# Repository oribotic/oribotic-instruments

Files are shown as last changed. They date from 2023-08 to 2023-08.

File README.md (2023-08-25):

Oribotic Instruments
====================

_Why wait for a Holtzman drive to fold space when you can start folding sound, now!_

Oribotic Instruments are multi-modal capacitive sensing instruments. They afford keypad style touch, pressure sensitive "soft touch" and capacitive sensing between electrode panels (rigid PCBs on flexible substrates such as textiles) otherwise known as _Fold Sensing_.

Copyright (c) 2023 Matthew Gardiner

MIT License

Software, hardware and instrument build contributions from: Simon Schmid, Dan Wilcox https://danomatika.com, Alexandre Bezri, Anna Oelsch

Description
-----------

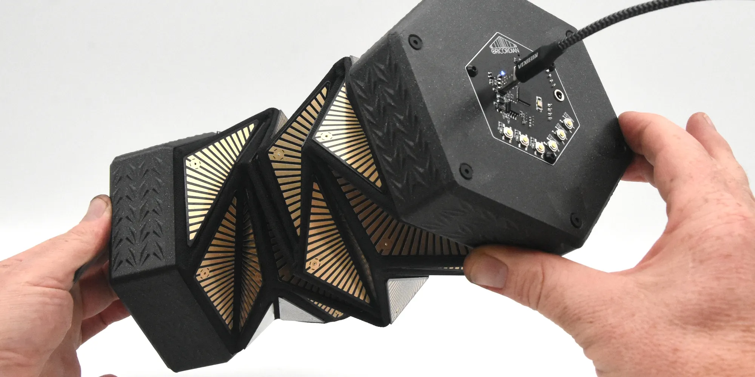
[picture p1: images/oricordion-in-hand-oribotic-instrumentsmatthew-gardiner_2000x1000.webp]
oribotic instruments


Our question for this work, What happens to our experience of space when we fold sound? is situated in our research into fundamental artistic methods for origami and robotics, following our central theme of Fold Sensing. Our conceptual approach is to invent foldable musical spaces rather than linear musical scores. The performer can explore the musical volume using choreographed folding paths and geometric gestures. 

Technically, oribotic instruments are layered electronics and textiles. The main elements are a capacitive sensor array from printed circuit board electrodes crafted as kinetic origami structures. The fold angles are captured in real-time and conveyed through a normalisation algorithm that adjusts for the non-linear capacitive response to the fold angle. These parametrised folded structures offer new affordances to interact, play and perform by contracting and expanding the fold geometry.

oribotic instruments multi-modal interations

Structure
---------

* `oribotic-instrument-atmega32u4`: instrument Arduino firmware
* `puredata`: [Puredata](https://puredata.info) abstraction library and templates

Installation & Build
--------------------

For info on building and configuring the Arduino firmware, see `oribotic-instrument-atmega32u4/README.md`

Usage
-----

Communication of the instrument with host systems is either via OSC (Open Sound Control) messages over a serial port *or* MIDI. The `comms-spec.md` markdown file lists the messaging specification for both types. Any software that can connect to a serial port or send/recieve MIDI messages should be able to receive from an Oribotic instrument.

Each foldable instrument is composed of a number of panels (8, 12, or 48) which are capcitively touch-sensitive and send the following for each panel in realtime:
* digital touch: on/off touch events
* bend: bend amount to the adjacent panel between unfolded and folded states (requires calibration)
* soft touch: amount of capacitive touch (think proximity and area/size)

As the instrument can be folded in an open-ended manner, calibration is required to send the bend low and high states: folded and unfolded, respectively. For instance, an 8 panel instrument could be folded in half, crosswise, in an origami pattern, etc the user only needs to tell the instrument when it is folded and unfolded. Panel bend values are then scaled to match.

### Puredata

An abstraction library and various templates and examples are provided both for the open-source [Puredata](https://puredata.info) computer music environment. 

Attribution
-----------

Funded through the FWF Austrian Science Fund, PEEK Program, ORI*botics on the art and science of origami and robotics https://orilab.art
Thank you to the Ars Electronica Futurelab https://ars.electronica.art/futurelab/
Thank you to [Josh Gardiner](https://github.com/NeuralSpaz) for pcb reviews and for being an awesome bro!

attribution logos

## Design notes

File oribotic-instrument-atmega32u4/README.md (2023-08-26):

Oribotic Instruments Arduino project
=====================================

Arduino based firmware for Oribotic instruments

Dependencies
------------

The project uses the following open source libraries:
* [MPR121](https://github.com/BareConductive/mpr121): MPR121 capacitive touch sense IC (modified, included in this repo)
* [OSC](https://github.com/CNMAT/OSC): (Open Sound Control) communication
* [MIDIUSB](https://github.com/arduino-libraries/MIDIUSB): MIDI communication over USB

Install the following libraries via the Arduino IDE Library Manager: OSC, MIDIUSB

Configuration
-------------

Configuration is set via defines at the top of `instrument_config.h`

Important compile-time settings are:

* `OSC`: 0 - disable, 1 - build with OSC serial communication
* `MIDI`: 0 - disable, 1 - build with MIDI communication
* `DEBUG_LEVEL`: 0 - off, 1 - error, 2 - info, 3 - debug
* `ORIGAMI`: YOSHIMURA - 8 panel, SUKI - 12 panel, KRESLING - 48 panel 
* `ROOTNOTE`: root MIDI note

The Arduino has too little memory for both OSC and MIDI communication, so you have to choose one and one only.

For example, this will run in MIDI mode:

~~~C
#define MIDI 1
#define OSC 0
~~~

This will run in OSC mode:

~~~C
#define MIDI 0
#define OSC 1
~~~

A bit further down in the file is:

~~~C
#define KRESLING 1
#define YOSHIMURA 2
#define SUKI 3
#define ORIGAMI YOSHIMURA
~~~

Update the last line, to KRESLING, YOSHIMURA or SUKI to suit the build of your instrument.

Associated config files for each instrument type:

* **KRESLING 48 panel** - see instrument_K48.h
* **SUKI 12 panel** - see instrument_S12.h
* **YOSHIMURA 8 panel** - see instrument_Y8.h

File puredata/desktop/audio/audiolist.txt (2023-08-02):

1 audio/flowcrash/Elkes.wav,
2 audio/flowcrash/8th-jubilee-rain-stereo.wav,
3 audio/flowcrash/Stillensteinklam.wav,
4 audio/flowcrash/bbc-milling-machine.wav,
5 audio/flowcrash/bbc-papermaking.wav,
6 audio/flowcrash/bbc-treadle-sewing-machine.wav.wav

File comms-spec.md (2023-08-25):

# AFFORDANCES

Using the MPR121's touch register in addition to filtered and baseline data from the MPR121, we identified four unique of gestural affordances from these instruments electrodes.

1. **Touch and Release**: the MPR121 is designed to identify touch and release interactions to each electrode. As a boolean value, these signals are useful for triggering samples or notes. 
2. **Soft Touch**: examining the filtered data following a touch and before a release affords a calculation of pressure on the sensor, as increased or decreased pressure is measurable, in small amounts. As an integer value with low range, small adjustments to volume on a sample, i.e. press harder = volume up, press lighter = volume down.
3. **Fold Sensing**: examining the filtered data at all times affords an approximation of proximity to another object. In the case of performance this can be the adjacent panel or the performer. The sensor gives no indication to the nature of the object, only that it is closer or further away. This makes for a very sensitive instrument. With a mathematical adjustment, derived from experimental test data with identical electrode pairs, we are able to estimate the angular position between the electrodes. The result is an integer value, reported as raw (MPR121->filtered) or bend range as defined during calibration, the value is generally scaled to 0-254 for OSC or 0-127 for MIDI and can be used for controlling of sound parameters. A simple example is the volume of a sound sample, a more complex use is to link the bend to one or more parametric audio operations. See Fold Sensing for detail on the sensing and calculation process.
4. **Fold Structure Sensing**: monitoring multiple electrodes to identify specific origami gestures  groups are defined using binary for code optimisation. Each panel occupies a position in the binary string. In the case of the Kresling origami, the panels are arranged in columns of 8 panels, where each binary digit refers to the one or off state of one of 8 panels, with six thereof. A panel group is defined by a switching a panel "on" in the group. Using binary, a single panel group only occupies six bytes in memory, and it describes the on or off state for every panel in the instrument. Similar to angle or bend sensing, a panel group is generally seen as a gesture recognition protocol, however the integer output is also scaled from 0-254 for OSC or 0-127 for MIDI. 

**potential function mappings**
 
- soft touch
	- control function with pressure
	- play note at velocity (volume)
- hard touch
	- play note at full velocity (volume)
- bend 
	- assignment to control function
- shape function
	- alter a global parameter

# PROTOCOL

## OSC

| Instrument | Channel [range] | Patch | Channel [range] | Synth | Channel [range] |
|:---|:---|:---|---|---|---|
| **sends** notes | /d [0-255] 0/1 | **receives** notes | /d [0-255] | | |
| **sends** control | /b /s [0-255] | **receives** control | | | |
| **send triggers**: | | **forwards triggers** | | | |
| **touch** | /d [0-255] 1/0 | **forwards** notes | 1 [custom] | **receives** notes | 1 [0-127] |
| **bend** | /b | **forwards** control | 1 [custom] | **receives** control  | 1 [0-127] |
| y8 | /b [0-7] | **forwards** control | 1 [custom] | **receives** control  | 1 [custom] |
| suki | /b [0-11] | **forwards** control | 1 [custom] | **receives** control  | 1 [custom] |
| oricordion | /b [0-47] | **forwards** control | 1 [custom] | **receives** control  | 1 [custom] |
| **soft touch** | /s | | | | |
| y8 | /s [8-15] | **forwards** control | 1 [custom] | **receives** control  | 1 [custom] |
| suki | /s [12-23] | **forwards** control | 1 [custom] | **receives** control  | 1 [custom] |
| oricordion | /s [48-95] | **forwards** control | 1 [custom] | **receives** control  | 1 [custom] |
| **panel group** | /s | | | | |
| y8 | /g [0-x] | **forwards** control | 1 [custom] | **receives** control  | 1 [custom] |
| suki | /g [0-x] | **forwards** control | 1 [custom] | **receives** control  | 1 [custom] |
| oricordion | /g [0-x] | **forwards** control | 1 [custom] | **receives** control  | 1 [custom] |
| **control ranges** | | | | | |
| y8 8 panels | 0 [0-15] | **forwards** control | 1 [custom] | **receives** control  | 1 [custom] |
| suki 12 panels | 0 [0-23] | **forwards** control | 1 [custom] | **receives** control  | 1 [custom] |
| oricordion  28 panels | 0 [0-95] | **forwards** control | 1 [custom] | **receives** control  | 1 [custom] |
| **receives** | /set/ | **sends to instrument**  | | | |
| set Hard | /setKey/hard/[key] | **sends to instrument**  | | | |
| set Soft | /setKey/soft/[key] | **sends to instrument**  | | | |
| set bendLO | /setKey/belo/[key] | **sends to instrument**  | | | |
| set bendHI | /setKey/behi/[key] | **sends to instrument**  | | | |
| set bendLO Hard Soft | /setKey/behs/[key] | **sends to instrument**  | | | |
| calibrate | /calibrate | **sends to instrument**  | | | |
| mode | /mode/[modenum] | **sends to instrument**  | | | |
| note set base | /root/[rootnote] | **sends to instrument**  | | | |
| major 0 / minor 1 | /scale/[0/1] | **sends to instrument**  | | | |
| mpr report | /mpr/[0-4] | **from instrument** | | | |
| set scale | /scale/[0-127] | **from instrument** | | | |
| set scale | /scale/[majo/mino] | **from instrument** | | | |

MIDI
----

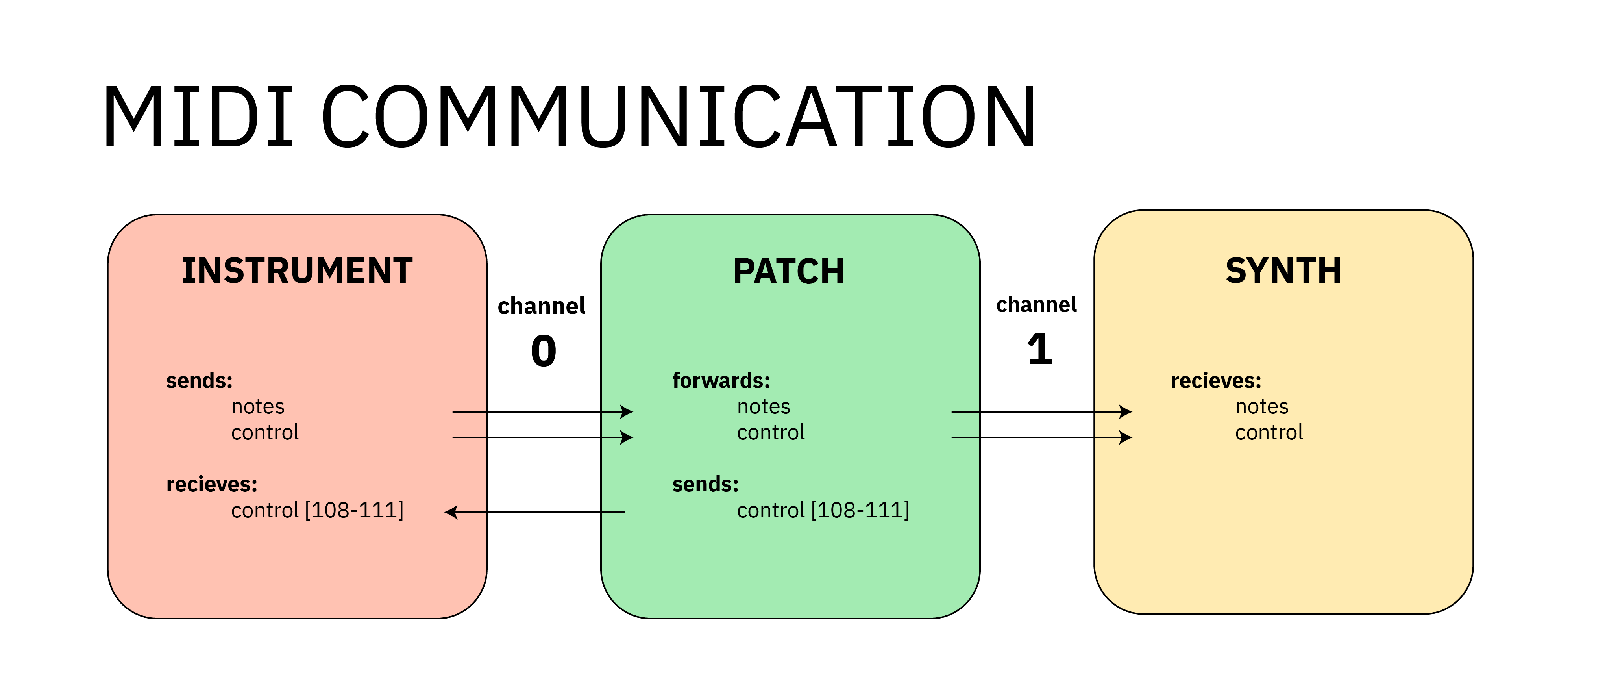
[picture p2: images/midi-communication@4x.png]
Midi Communication diagram


| Instrument | Channel [range] | Patch | Channel [range] | Synth | Channel [range] |
|:---|:---|:---|---|---|---|
| **sends** notes | 0  [0-127] | **receives** notes | 0 [0-127] | | |
| **sends** control | 0  [0-95] | **receives** control | 0 [0-127] | | |
| **send triggers**: | | **forwards triggers** | | | |
| **touch** | noteon/noteoff  | **forwards** notes | 1 [0-127] | **receives** notes | 1 [0-127] |
| **bend** | control, value  | | | | |
| y8 | 0 [0-7] | **forwards** control | 1 [custom] | **receives** control  | 1 [custom] |
| suki | 0 [0-11] | **forwards** control | 1 [custom] | **receives** control  | 1 [custom] |
| oricordion | 0 [0-47] | **forwards** control | 1 [custom] | **receives** control  | 1 [custom] |
| **soft touch** | control, value  | | | | |
| y8 | 0 [8-15] | **forwards** control | 1 [custom] | **receives** control  | 1 [custom] |
| suki | 0 [12-23] | **forwards** control | 1 [custom] | **receives** control  | 1 [custom] |
| oricordion | 0 [48-95] | **forwards** control | 1 [custom] | **receives** control  | 1 [custom] |
| **control ranges** | | | | | |
| y8 8 panels | 0 [0-15] | **sends to instrument**  | | | |
| suki 12 panels | 0 [0-23] | **sends to instrument**  | | | |
| oricordion  28 panels | 0 [0-95] | **sends to instrument**  | | | |
| **panel group** | | | | | |
| y8 8 panels | 0 [100-x] | **sends to instrument**  | | | |
| suki 12 panels | 0 [100-x] | **sends to instrument**  | | | |
| oricordion  28 panels | 0 [100-x] | **sends to instrument**  | | | |
| **receives** | 0 [111] | **sends to instrument**  | | | |
| set Hard | 0 [111] 0 | **sends to instrument**  | | | |
| set Soft | 0 [111] 5 | **sends to instrument**  | | | |
| set bendLO | 0 [111] 10 | **sends to instrument**  | | | |
| set bendHI | 0 [111] 15 | **sends to instrument**  | | | |
| set bendLO Hard Soft | 0 [111] 20 | **sends to instrument**  | | | |
| calibrate | 0 [111] 100 | **sends to instrument**  | | | |
| mode | 0 [110] [0-127] | **sends to instrument**  | | | |
| note set base | 0 [109] [0-127] | **sends to instrument**  | | | |
| set scale major 0 / minor | 0 [108] [0-1] | **sends to instrument**  | | | |
| mpr121 report A | 0 [107] [0-1] | **sends to instrument**  | | | |
| mpr121 report B | 0 [106] [0-1] | **sends to instrument**  | | | |
| mpr121 report C | 0 [105] [0-1] | **sends to instrument**  | | | |
| mpr121 report D | 0 [104] [0-1] | **sends to instrument**  | | | |
| set scale | 0 [103] [0-7] | **sends to instrument**  | | | |
| report notes in scale | 0 [103][p][note]| **from instrument** | | | |
| report scale type | 0 [103] 100-107 | **from instrument** | | | |
| FFI | 0 [112] [0-5] | **sends to instrument**  | | | |
| SF1 | 0 [113] [0-5] | **sends to instrument**  | | | |
| Interval | 0 [114] [0-5] | **sends to instrument**  | | | |
| CDT | 0 [115] [0-5] | **sends to instrument**  | | | |
| SF1 | 0 [113] [0-5] | **sends to instrument**  | | | |

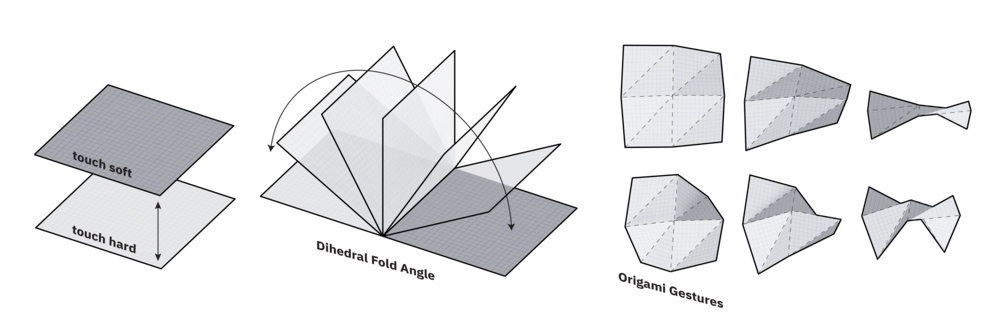
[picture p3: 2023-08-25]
images/multi-modal-composite-1000px.webp

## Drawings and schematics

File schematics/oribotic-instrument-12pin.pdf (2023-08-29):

## ATMEGA32u4 POWER

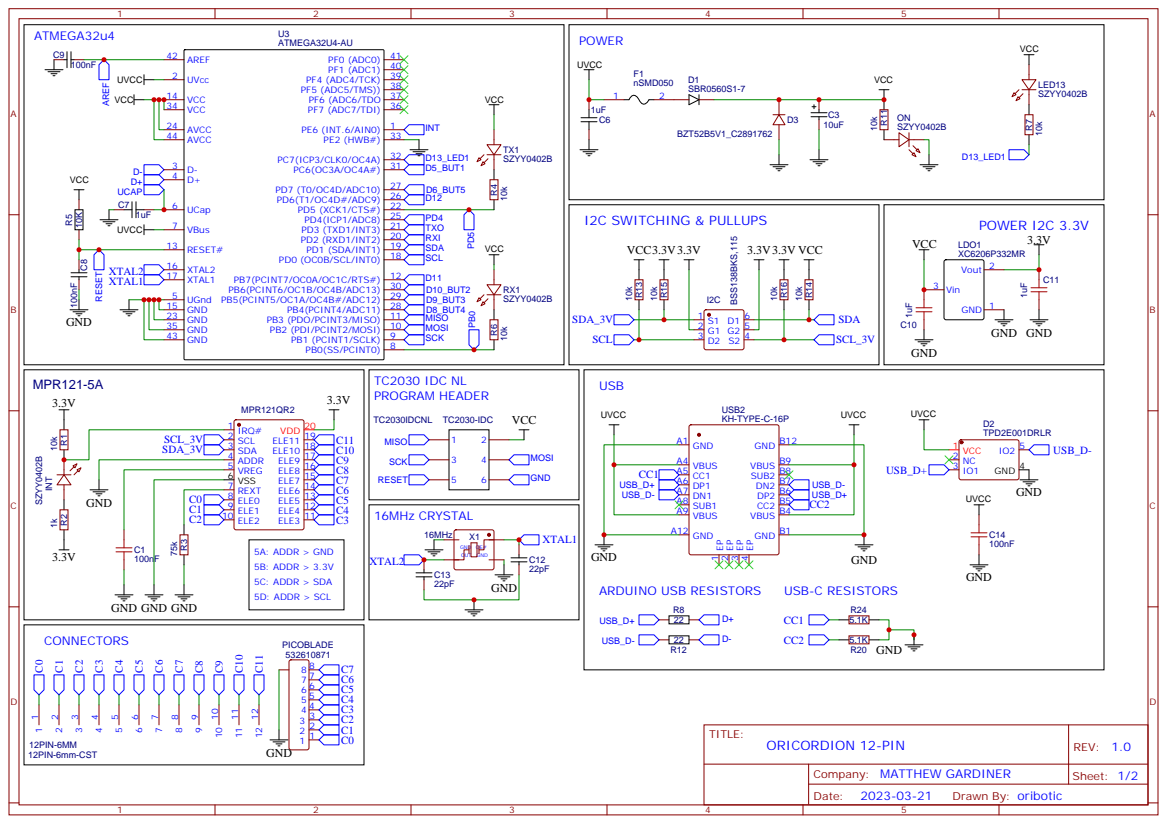
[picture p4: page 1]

PB7(PCINT7/OC0A/OC1C/RTS#) 12
PB2 (PDI/PCINT2/MOSI) 10 PB3 (PDO/PCINT3/MISO) 11 PB4(PCINT4/ADC11) 28 PB5(PCINT5/OC1A/OC4B#/ADC12) 29 PB6(PCINT6/OC1B/OC4B/ADC13) 30

## BUTTONS / RESET

## ATMEGA32-U4 MU build variant

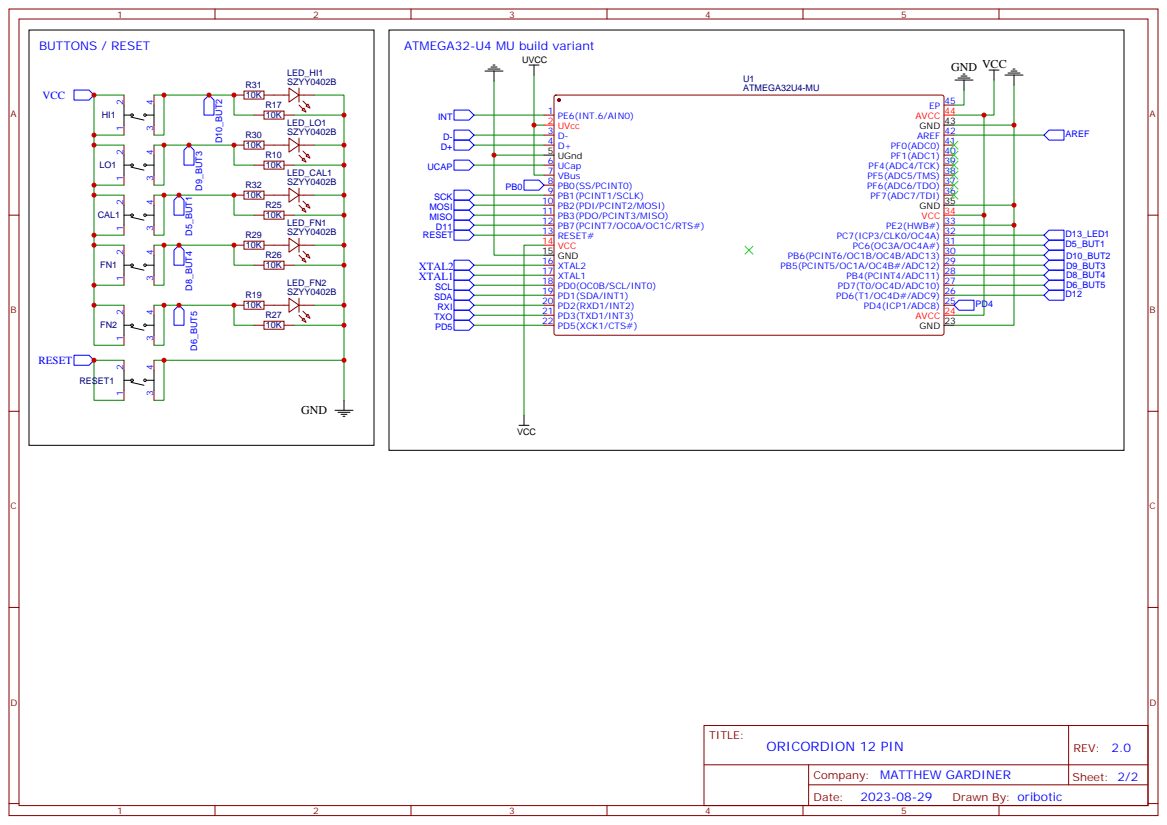
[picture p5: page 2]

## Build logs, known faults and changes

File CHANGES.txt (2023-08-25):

0.2.0: 2023 Aug 25

firmware
* fixed: a couple build errors
* fixed: inconsistent panel ids between OSC and MIDI
* added: MODE_SOFT_VELOCITY for sending /s data via midi velocity for /d
* added: soft touch to send function
* added: sending control signals to the next count of panels up. i.e: from 8-15 for Y8
* added: receive handling for float arguments, this improves flexibility when working with pd's built-in osc objects
* changed: OSC messaging protocol for instrument signals ie. /d/0 -> /d 0
* changed: OSC d range back to 0-255 for consistency with b and s
* changed: volume scaling from input signal from 8bit to 7bits for midi / osc compatibility
* changed: inverted the velocity logic for /s, now 127 is hard and 0 is soft
* changed: send /key and /n with id as a
* changed: check range when setting mode, scale, & root
* changed: MPR library sources now in src/MPR121 subdir
* removed: MIDIUSB sources from project in favor of installing via Arduino IDE

puredata
* puredata: added oi abstraction library
* added: mode 6 for MODE_SOFT_VELOCITY
* changed: volume scaling from 0-255 to 0-127
* changed: send soft -> send /s
* changed: send bend -> send /b
* changed: ctrlin to numerate each /b or /s signal for clarity in the patch
* changed: various puredata template improvements and bugfixes
* removed: template osc and rjlib external dependencies

docs
* added: pd vanilla setup dependency and install steps
* added: commnication spec info markdown info and diagram
* added: readme sections and changelog

other
* added: Makefile with oi-zip target to create oi abs library release zips

0.1.0: 2023 Aug 14

initial alpha: arduino project & puredata templates

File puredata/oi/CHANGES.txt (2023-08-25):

0.3.0: 2023 Aug 25

* added oi.o.instrument midi output range option, default is 0-255

0.2.0: 2023 Aug 24

* added support for multiple MIDI devices via settable channel creation arg in
  oi.m.instrument, oi.m.control, & oi.m.panel
* added oi.m.routechan helper

0.1.0: 2023 Aug 23

initial alpha

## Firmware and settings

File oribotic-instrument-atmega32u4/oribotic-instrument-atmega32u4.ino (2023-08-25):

/*
 * Copyright (c) 2023 Matthew Gardiner
 *
 * MIT License.
 * For information on usage and redistribution, and for a DISCLAIMER OF ALL
 * WARRANTIES, see the file, "LICENSE.txt," in this distribution.
 *
 * See https://github.com/oribotic/oribotic-instruments for documentation
 *
 */
#include "src/MPR121/MPR121.h"
#include <Wire.h>

// BASIC INSTRUMENT CONFIG 
#include "instrument_config.h"
#include "music.scales.h"
// ORICORDION FUNCTIONS
#include "ORICORD.h"

// #include <EEPROM.h>
#define __AVR_ATmega32U4__

#ifndef _BV
  #define _BV(bit) (1 << (bit))
#endif

#if MIDI == 1
  #include "MIDIUSB.h"
  #include "MIDIUSB_Defs.h"
  #include "comms.midi.h"
#endif

#if OSC == 1
  #include "comms.osc.h"
#endif

#define REVERSED 0
#define ARR_LEN(x) (sizeof(x) / sizeof(x[0]))

// --------------------------------------------------------------------     SETUP
void setup()
{
  // put your setup code here, to run once:
  #if MIDI == 1
    Serial.begin(115200);
  #endif
  #if OSC == 1
    SLIPSerial.begin(115200);
    #if ARDUINO >= 100
      while (!Serial1)
        ; // Leonardo "feature"
    #endif
  #endif

  pinMode(LED1, OUTPUT);
  digitalWrite(LED1, 1);
  pinMode(CAL_BTN, INPUT);   // button 1
  pinMode(HI_BTN, INPUT);    // button 2
  pinMode(LO_BTN, INPUT);    // button 3
  #if BTN_COUNT == 5
    pinMode(FN1_BTN, INPUT); // button 2
    pinMode(FN2_BTN, INPUT); // button 3
  #else
    pinMode(LED2, OUTPUT);
    pinMode(LED3, OUTPUT);
  #endif

  setupMPR();
  delay(500);
}

// --------------------------------------------------------------------     MAIN LOOP

void loop() {
  #if OSC == 1
    if (SLIPSerial.available() > 0)
      rxOSC();
  #endif

  #if MIDI == 1
    rxMIDI();
  #endif

  uint8_t i;

  #if MPRCOUNT > 0
    MPR121_0.updateAll();
  #endif
  #if MPRCOUNT > 1
    MPR121_1.updateAll();
  #endif
  #if MPRCOUNT > 2
    MPR121_2.updateAll();
  #endif
  #if MPRCOUNT > 3
    MPR121_3.updateAll();
  #endif

  checkbuttons();

  for (i = 0; i < PINCOUNT; i++)
  {
    switch (mode)
    {
      case MODE_SERIAL_DEBUG:         // 0
        serialDebug(i, 0);
        break;
      case MODE_SERIAL_DEBUG_RAW:     // 1
        serialDebug(i, 1);
        break;
      case MODE_RAW:                  // 2
        raw(i);
        break;
      case MODE_NORMALISED:           // 3
        touchPlay(i);
        break;
      case MODE_RAW_PLUS_NORMALISED:  // 4
        touchPlay(i);
        raw(i); 
        break;
      case MODE_TOUCH_PLAY:           // 5
      case MODE_SOFT_VELOCITY:        // 6 has adjustments in send() for midi
        touchPlay(i);
        break;

    }
  }
  #ifdef PANELGROUPS
  if (usePanelGroups)
  {
    updatePanelGroups();
  }
  #endif  
  delay(intervaldelay);
}

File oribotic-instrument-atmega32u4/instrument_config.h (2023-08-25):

/*
 * Copyright (c) 2023 Matthew Gardiner
 *
 * MIT License.
 * For information on usage and redistribution, and for a DISCLAIMER OF ALL
 * WARRANTIES, see the file, "LICENSE.txt," in this distribution.
 *
 * See https://github.com/oribotic/oribotic-instruments for documentation
 *
 */
#ifndef INSTRUMENT_CONFIG_H
#define INSTRUMENT_CONFIG_H

#include <Arduino.h>

// only switch one on at a time
#define MIDI 1
#define OSC 0

#if MIDI
#define INTERVALDELAY 5
#endif
#if OSC 
#define INTERVALDELAY 10
#endif 

extern uint8_t intervaldelay;

// soft lo offset is the reading below bendLO that soft starts working
// for PCBS SOFT_LOW_OFFSET 50, LO_HARD_OFFSET 100

#define DEBUG_LEVEL 2   // 0 - 3 
#define TEXTILE 0
#define KRESLING 1
#define YOSHIMURA 2
#define SUKI 3
#define ORIGAMI YOSHIMURA

#define SOFT_FILTER_LIMIT 200

#define ROOTNOTE 60

#define SETUP_FUNCTIONS 1

#define MODE_DEFAULT 5
#define MODE_SERIAL_DEBUG 0 // useful only for serial output checks
#define MODE_SERIAL_DEBUG_RAW 1 // useful only for serial output checks
#define MODE_RAW 2 // works for midi and osc
#define MODE_NORMALISED 3 // works for midi and osc
#define MODE_RAW_PLUS_NORMALISED 4 // only works on osc 
#define MODE_TOUCH_PLAY 5 // works on midi and osc - default mode
#define MODE_SOFT_VELOCITY 6 // works on midi and osc
//#define MODE_SERIAL_DEBUG_BYTES 5 // no longer used 
#define MAXMODE 6 // max allowed mode index

#if ORIGAMI==YOSHIMURA
    #include "instrument_Y8.h"
#endif
#if ORIGAMI==KRESLING
    #include "instrument_K48.h"
#endif  
#if ORIGAMI==SUKI
    #include "instrument_S12.h"
#endif  

#endif

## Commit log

2023-08-14 S12-osc-template: fixed path to [io.slipserial] by prepending oi/, fixed pack MPR* bad type by replacing [pack MPR* 0] with [0(; fixed stop audio button send audiostop -> stopaudio; disconnected [dac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
2023-08-14 Y8-osc-template: fixed path to [io.slipserial] by prepending oi/; disconnected [dac~] from [r loop] to fix bang error; send invert 0 and mixnumber 1 on load to avoid no audio after loading samples an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
2023-08-14 Y8-midi-template: disconnected [dac~] from [r loop] to fix bang error; send invert 0 and mixnumber 1 on load to avoid no audio after loading samples and starting audio the first time
2023-08-16 soft touch - /d velocity mode
    firmware:
    added: MODE_SOFT_VELOCITY for sending /s data via midi velocity for /d
    changed: inverted the velocity logic for /s, now 127 is hard and 0 is soft
    puredata:
    added: mode 6 for MODE_SOFT_VELOCITY
    [ORICORD.cpp, instrument_config.h, oribotic-instrument-atmega32u4.ino]
2023-08-17 ignore arduino.json
2023-08-23 firmware: fixed build error for MIDI mode due to wrong var names
    [comms.midi.cpp]
2023-08-23 firmware: revert midi channel to 0
    [ORICORD.cpp]
2023-08-24 oi 0.2.0: added support for multi MIDI devices via settable channel
2023-08-25 add basic config overview to arduino readme
2023-08-25 formware: removed included MIDIUSB in favor of installing via Arduino IDE
2023-08-25 puredata: renamed subdir to desktop (lower case), renamed template helper lib folder from oi to lib, added m_scale to removed rjlib dependency, fixed sample table loading order, fixed table graphing 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
    [instrument_config.h]
2023-08-25 bugfix: orikeys
    updated midi / osc struct orikey for Y8 instrument
    [MPR121.cpp, ORICORD.cpp, comms.midi.cpp]
2023-08-29 added board schematics
2023-08-29 added gerber files
    v2 gerber files for 12 pin oribotic instrument
    [Drill_NPTH_Through.DRL, Drill_PTH_Through.DRL, Drill_PTH_Through_Via.DRL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]
